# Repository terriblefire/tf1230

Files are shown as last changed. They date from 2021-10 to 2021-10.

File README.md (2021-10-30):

# tf1230

TF1230 source files. 

Released in Creative Commons CC-BY-ND license. 

This is a NO DERIVATIVES LICENSE. You cannot modify it and distribute the modified version.

TF1230 is distributed with absolutely no warranty. If you make a mistake you could blow up your A1200. I take no responsibility for this. 

The TF1230 is an 030 accelerator fixed at 50Mhz with 64Mb of SDRAM (128Mb possible), and is intended to work with CF cards or IDE2SD card type devices. The IDE interface does not work with long cables. It is intended to be CHEAP Because thats pretty much all Amiga users care about. You need the ehide.device to use the onboard ide.

There was a design decision to make with the TF ide. Do we make it work as the default ide device and break PCMCIA support, do we add a rom on the card (and more expense) or do we just provide a driver that you can put in a cheap rom and run that way (or just run from disk). I figured the cheapest and least invasive option was the best for a home build solution.

**Before you start building :- You can buy these from Supaduper & AlenPPC (AmiBay) completely built for less than it will cost you to buy the parts and the time it will take you if you bill your time at minimum wage.**

Also do not ask me to reroute the board to a different DRC so you can use your local boardhouse. I dont feel like spending 100 hours of my time to save you $10. The DRC on this board is 7-7-7 and any boardhouse that doesnt totally suck can do this. Also it 4 layer and dont ask if i can be made 2 layer. The answer is no. 

If you need help with this the best place to get it is the exxos forum https://www.exxoshost.co.uk/forum/ 

The SDRAM Controller is derived from my Archie core and the clock controller code is designed to simulate a PLL with adjustable phase. 

This is not an exercise in German over engineering. Its engineered to do an exact task and nothing more. You will need to do the timing fixes or put a clock buffer on the clock line on this board. I didnt do this because i believe that the timing changes are needed on Amigas and not doing them is bad for them long term. Cards that let you get away without doing it are doing you a diservice. It would be like cards letting you go longer without a recap. Its 

That said you are free to sell this on your webshop provided you give credit and do not vastly overprice it. However CE marking is your own issue not mine. AmigaKit may not sell this ever... anyone else can. 

On the other hand if you have an actual firmware bugfix send me a pull request with testing evidence. It will be appreciated greatly. 

For crashes please check that the crash doesnt happen in WinUAE for a A1200 with A1200 IDE and 64MB ZIII Ram before making a bug report. Most of the crashes we have seen over the years are repeatable in that environment.

The purpose of this card is for you to get more enjoyment from your Amiga for very little money. Please do that.

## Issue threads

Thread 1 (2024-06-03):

Possible to assert AS towards motherboard only if access is to low 16 MB?

niklasekstrom, 2024-06-03:
Hi @terriblefire,

A user of PicoWyfy (https://github.com/niklasekstrom/picowyfy) that has an issue when it is used together with TF1232 pointed me to this forum post: https://www.exxosforum.co.uk/forum/viewtopic.php?p=91790

Would it make sense to update the logic for the AS signal towards the motherboard, by only asserting it if the top 8 bits of the address bus is 8'h00?

Perhaps something like: `AS20_D <= AS30 | ~SPEED_D | (A[31:24] != 8'h00);`
(taken from https://github.com/terriblefire/tf1230/blob/main/rtl/main_top.v#L274)

I'm thinking that this should prevent SPARE_CS from being asserted when an access is made to some address $xxD8yyyy where xx != 00.

I should say that I only looked at the rtl very quickly, so this may be incorrect for multiple reasons.

terriblefire, 2024-06-03:
i spent an evening trying this with Rob Cranley. I could do that but the CS lines do not depend on AS. They decode whether or not AS is asserted

niklasekstrom, 2024-06-03:
Oh, right, sorry. I looked in this document, https://www.amigawiki.org/lib/exe/fetch.php?media=de:parts:gayle_specification.pdf, where it says:

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
(`Chip select is based purely on address decode and _AS`)

But then when looking in this document, https://github.com/nonarkitten/amiga_replacement_project/blob/master/gayle/gayle_r5.pdf, it is as you say, SPARE_CS is based purely on address decode.

However, in that last document (gayle_r5.pdf) it also looks like AS needs to be asserted for IORD to be asserted. So keeping AS negated should prevent IORD from becoming asserted, and so should prevent the incorrect read access from the clockport device.

Actually, although not strictly necessary, perhaps DS20 should also be gated by A[31:24] == 8'h00?

`DS20_D <= DS30 | ~SPEED_D | (A[31:24] != 8'h00);`
(From https://github.com/terriblefire/tf1230/blob/main/rtl/main_top.v#L275)

niklasekstrom, 2024-06-03:
Would it be easy (enough) for you to compile a firmware for TF1232 using these two changes (gating AS20_D and DS20_D)? In that case perhaps the guy who has the TF1232 + PicoWyfy combo could try that firmware and see if it helps.

terriblefire, 2024-06-03:
I can but you need to understand it's irrelevant because SPEED_D is asserted when talking to fastram and that already prevents AS going low. I've investigated this issue thoroughly already.

niklasekstrom, 2024-06-03:
SPEED_D (via ram_decode) doesn't seem to take A[26:24] into account though?

terriblefire, 2024-06-03:
0x08D80000 would not assert AS/DS because A27 is asserted. Anything in the range 08xxx xxxx will not assert AS. I've already measured this looking for this specific issue.

niklasekstrom, 2024-06-03:
Ah right, so the address 0x07D80000 would cause a problem though?

terriblefire, 2024-06-03:
Nothing in AmigaOS should look at that address.

terriblefire, 2024-06-03:
BTW. You can just try this yourself with the TF1230 code. The TF1232 is compatible with the TF1230 firmwares. You just dont get the FPU

niklasekstrom, 2024-06-03:
Do you have the build environment set up so that it's very easy for you to compile a new firmware with those changes?

If not then I could try to set it up myself. But if I do then I still don't have a way to compile the TF1232 firmware with FPU support, so the user doesn't have any way to restore the firmware to get FPU support back.

The user reported that the problem showed up in two demos, so the demos may make accesses that AmigaOS wouldn't.

Just to be clear, I have no idea if the problem has anything to do with the TF firmware, I'm just trying to think of things to test, to help the user out.

terriblefire, 2024-06-03:
I can put a test fw here. later if you need.

The reason i didnt want to blank off AS here is because technically the CPU slot is 32bit address bus and there are CFGIN/OUT pins on it. I guess most CPU cards wont obey the rules but you can put a full Z3 32bit bus card between all the TF cards and an amiga they will work. i.e. it will be able to address a card at 0x40000000 for example

niklasekstrom, 2024-06-03:
I checked with the guy, and he knows how to update the TF firmware as he did it recently. So if you could build a firmware with those changes then that would be most appreciated! And very interesting to see what happens.

niklasekstrom, 2024-06-04:
I managed to compile the firmware in this repo with the changes mentioned. But apparently there are other issues with the user's Amiga, so he hasn't been able to test the changes. Perhaps the crashes were related to the other issues to begin with.

I'll close this issue for now, and if he later manages to test the changes then I will add information about how it went.

terriblefire, 2024-06-04:
Ok thanks. if we can actually pin down an issue i'm happy to delve in and fix

Closed 2024-06-04.

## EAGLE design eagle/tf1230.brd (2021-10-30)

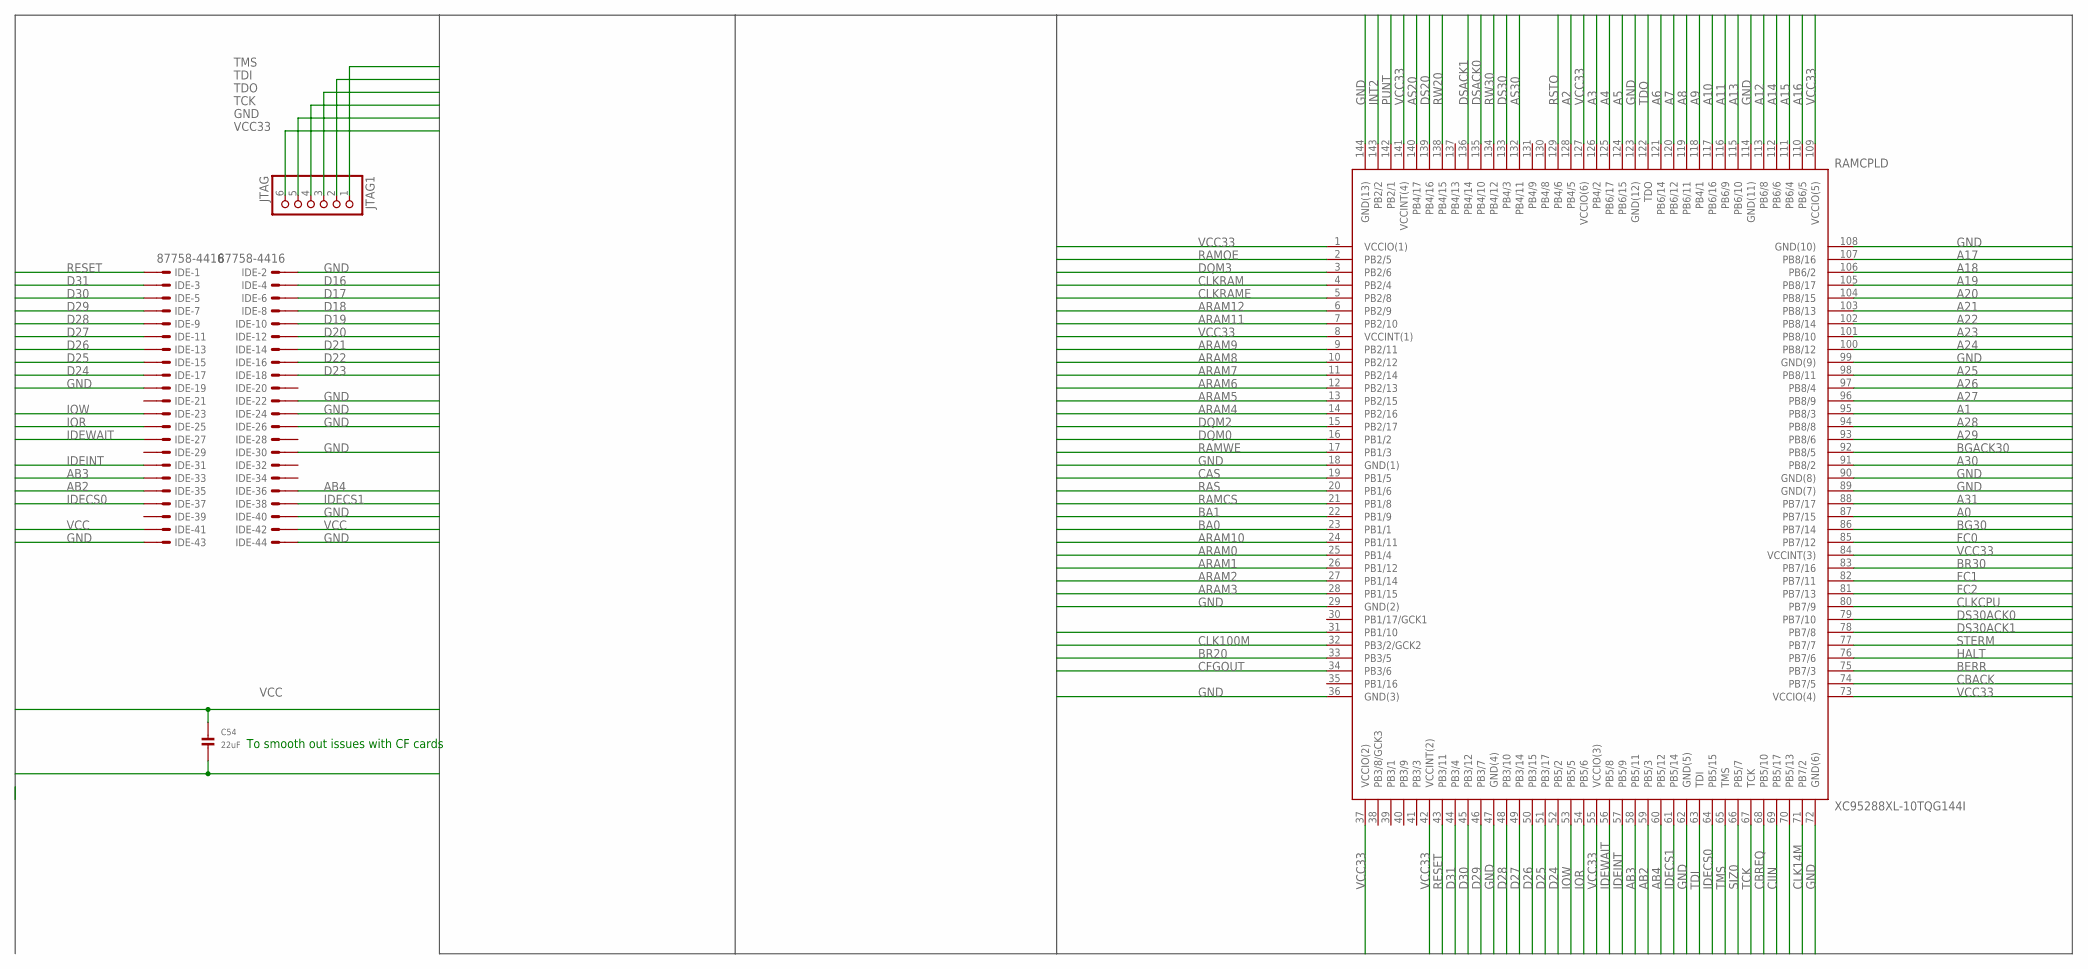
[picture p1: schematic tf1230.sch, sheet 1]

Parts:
C54: 22uF; 1206
IDE: 87758-4416
JTAG1: JTAG; 1X06_ROUND
RAMCPLD: XC95288XL-10TQG144I; SAMACSYS_PARTS_QFP50P2200X2200X160-144N

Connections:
A0: RAMCPLD.87 (PB7/15); also elsewhere on the board
A1: RAMCPLD.95 (PB8/3); also elsewhere on the board
A2: RAMCPLD.128 (PB4/5); also elsewhere on the board
A3: RAMCPLD.126 (PB4/2); also elsewhere on the board
A4: RAMCPLD.125 (PB6/17); also elsewhere on the board
A5: RAMCPLD.124 (PB6/15); also elsewhere on the board
A6: RAMCPLD.121 (PB6/14); also elsewhere on the board
A7: RAMCPLD.120 (PB6/12); also elsewhere on the board
A8: RAMCPLD.119 (PB6/11); also elsewhere on the board
A9: RAMCPLD.118 (PB4/1); also elsewhere on the board
A10: RAMCPLD.117 (PB6/16); also elsewhere on the board
A11: RAMCPLD.116 (PB6/9); also elsewhere on the board
A12: RAMCPLD.113 (PB6/8); also elsewhere on the board
A13: RAMCPLD.115 (PB6/10); also elsewhere on the board
A14: RAMCPLD.112 (PB6/6); also elsewhere on the board
A15: RAMCPLD.111 (PB6/4); also elsewhere on the board
A16: RAMCPLD.110 (PB6/5); also elsewhere on the board
A17: RAMCPLD.107 (PB8/16); also elsewhere on the board
A18: RAMCPLD.106 (PB6/2); also elsewhere on the board
A19: RAMCPLD.105 (PB8/17); also elsewhere on the board
A20: RAMCPLD.104 (PB8/15); also elsewhere on the board
A21: RAMCPLD.103 (PB8/13); also elsewhere on the board
A22: RAMCPLD.102 (PB8/14); also elsewhere on the board
A23: RAMCPLD.101 (PB8/10); also elsewhere on the board
A24: RAMCPLD.100 (PB8/12); also elsewhere on the board
A25: RAMCPLD.98 (PB8/11); also elsewhere on the board
A26: RAMCPLD.97 (PB8/4); also elsewhere on the board
A27: RAMCPLD.96 (PB8/9); also elsewhere on the board
A28: RAMCPLD.94 (PB8/8); also elsewhere on the board
A29: RAMCPLD.93 (PB8/6); also elsewhere on the board
A30: RAMCPLD.91 (PB8/2); also elsewhere on the board
A31: RAMCPLD.88 (PB7/17); also elsewhere on the board
AB2: IDE.35, RAMCPLD.59 (PB5/3)
AB3: IDE.33, RAMCPLD.58 (PB5/11)
AB4: IDE.36, RAMCPLD.60 (PB5/12)
ARAM0: RAMCPLD.25 (PB1/4); also elsewhere on the board
ARAM1: RAMCPLD.26 (PB1/12); also elsewhere on the board
ARAM2: RAMCPLD.27 (PB1/14); also elsewhere on the board
ARAM3: RAMCPLD.28 (PB1/15); also elsewhere on the board
ARAM4: RAMCPLD.14 (PB2/16); also elsewhere on the board
ARAM5: RAMCPLD.13 (PB2/15); also elsewhere on the board
ARAM6: RAMCPLD.12 (PB2/13); also elsewhere on the board
ARAM7: RAMCPLD.11 (PB2/14); also elsewhere on the board
ARAM8: RAMCPLD.10 (PB2/12); also elsewhere on the board
ARAM9: RAMCPLD.9 (PB2/11); also elsewhere on the board
ARAM10: RAMCPLD.24 (PB1/11); also elsewhere on the board
ARAM11: RAMCPLD.7 (PB2/10); also elsewhere on the board
ARAM12: RAMCPLD.6 (PB2/9); also elsewhere on the board
AS20: RAMCPLD.140 (PB4/17); also elsewhere on the board
AS30: RAMCPLD.132 (PB4/11); also elsewhere on the board
BA0: RAMCPLD.23 (PB1/1); also elsewhere on the board
BA1: RAMCPLD.22 (PB1/9); also elsewhere on the board
BERR: RAMCPLD.75 (PB7/3); also elsewhere on the board
BG30: RAMCPLD.86 (PB7/14); also elsewhere on the board
BGACK30: RAMCPLD.92 (PB8/5); also elsewhere on the board
BR20: RAMCPLD.33 (PB3/5); also elsewhere on the board
BR30: RAMCPLD.83 (PB7/16); also elsewhere on the board
CAS: RAMCPLD.19 (PB1/5); also elsewhere on the board
CBACK: RAMCPLD.74 (PB7/5); also elsewhere on the board
CBREQ: RAMCPLD.68 (PB5/10); also elsewhere on the board
CFGOUT: RAMCPLD.34 (PB3/6); also elsewhere on the board
CIIN: RAMCPLD.69 (PB5/17); also elsewhere on the board
CLK14M: RAMCPLD.71 (PB7/2); also elsewhere on the board
CLK100M: RAMCPLD.32 (PB3/2/GCK2); also elsewhere on the board
CLKCPU: RAMCPLD.80 (PB7/9); also elsewhere on the board
CLKRAM: RAMCPLD.4 (PB2/4); also elsewhere on the board
CLKRAME: RAMCPLD.5 (PB2/8); also elsewhere on the board
D16: IDE.4; also elsewhere on the board
D17: IDE.6; also elsewhere on the board
D18: IDE.8; also elsewhere on the board
D19: IDE.10; also elsewhere on the board
D20: IDE.12; also elsewhere on the board
D21: IDE.14; also elsewhere on the board
D22: IDE.16; also elsewhere on the board
D23: IDE.18; also elsewhere on the board
D24: IDE.17, RAMCPLD.52 (PB5/2); also elsewhere on the board
D25: IDE.15, RAMCPLD.51 (PB3/17); also elsewhere on the board
D26: IDE.13, RAMCPLD.50 (PB3/15); also elsewhere on the board
D27: IDE.11, RAMCPLD.49 (PB3/14); also elsewhere on the board
D28: IDE.9, RAMCPLD.48 (PB3/10); also elsewhere on the board
D29: IDE.7, RAMCPLD.46 (PB3/7); also elsewhere on the board
D30: IDE.5, RAMCPLD.45 (PB3/12); also elsewhere on the board
D31: IDE.3, RAMCPLD.44 (PB3/4); also elsewhere on the board
DQM0: RAMCPLD.16 (PB1/2); also elsewhere on the board
DQM1: RAMCPLD.31 (PB1/10); also elsewhere on the board
DQM2: RAMCPLD.15 (PB2/17); also elsewhere on the board
DQM3: RAMCPLD.3 (PB2/6); also elsewhere on the board
DS20: RAMCPLD.139 (PB4/16); also elsewhere on the board
DS30: RAMCPLD.133 (PB4/3); also elsewhere on the board
DS30ACK0: RAMCPLD.79 (PB7/10); also elsewhere on the board
DS30ACK1: RAMCPLD.78 (PB7/8); also elsewhere on the board
DSACK0: RAMCPLD.135 (PB4/10); also elsewhere on the board
DSACK1: RAMCPLD.136 (PB4/14); also elsewhere on the board
FC0: RAMCPLD.85 (PB7/12); also elsewhere on the board
FC1: RAMCPLD.82 (PB7/11); also elsewhere on the board
FC2: RAMCPLD.81 (PB7/13); also elsewhere on the board
GND: C54.2, IDE.2, IDE.19, IDE.22, IDE.24, IDE.26, IDE.30, IDE.40, IDE.43, IDE.44, JTAG1.5, RAMCPLD.18 (GND(1)), RAMCPLD.29 (GND(2)), RAMCPLD.36 (GND(3)), RAMCPLD.47 (GND(4)), RAMCPLD.62 (GND(5)), RAMCPLD.72 (GND(6)), RAMCPLD.89 (GND(7)), RAMCPLD.90 (GND(8)), RAMCPLD.99 (GND(9)), RAMCPLD.108 (GND(10)), RAMCPLD.114 (GND(11)), RAMCPLD.123 (GND(12)), RAMCPLD.144 (GND(13)); also elsewhere on the board
HALT: RAMCPLD.76 (PB7/6); also elsewhere on the board
IDECS0: IDE.37, RAMCPLD.64 (PB5/15)
IDECS1: IDE.38, RAMCPLD.61 (PB5/14)
IDEINT: IDE.31, RAMCPLD.57 (PB5/9); also elsewhere on the board
IDEWAIT: IDE.27, RAMCPLD.56 (PB5/8); also elsewhere on the board
INT2: RAMCPLD.143 (PB2/2); also elsewhere on the board
IOR: IDE.25, RAMCPLD.54 (PB5/6)
IOW: IDE.23, RAMCPLD.53 (PB5/5)
PUNT: RAMCPLD.142 (PB2/1); also elsewhere on the board
RAMCS: RAMCPLD.21 (PB1/8); also elsewhere on the board
RAMOE: RAMCPLD.2 (PB2/5); also elsewhere on the board
RAMWE: RAMCPLD.17 (PB1/3); also elsewhere on the board
RAS: RAMCPLD.20 (PB1/6); also elsewhere on the board
RESET: IDE.1, RAMCPLD.43 (PB3/11); also elsewhere on the board
RSTO: RAMCPLD.129 (PB4/6); also elsewhere on the board
RW20: RAMCPLD.138 (PB4/15); also elsewhere on the board
RW30: RAMCPLD.134 (PB4/12); also elsewhere on the board
SIZ0: RAMCPLD.66 (PB5/7); also elsewhere on the board
SIZ1: RAMCPLD.70 (PB5/13); also elsewhere on the board
STERM: RAMCPLD.77 (PB7/7); also elsewhere on the board
TCK: JTAG1.4, RAMCPLD.67 (TCK)
TDI: JTAG1.2, RAMCPLD.63 (TDI)
TDO: JTAG1.3, RAMCPLD.122 (TDO)
TMS: JTAG1.1, RAMCPLD.65 (TMS)
VCC: C54.1, IDE.41, IDE.42; also elsewhere on the board
VCC33: JTAG1.6, RAMCPLD.1 (VCCIO(1)), RAMCPLD.8 (VCCINT(1)), RAMCPLD.37 (VCCIO(2)), RAMCPLD.42 (VCCINT(2)), RAMCPLD.55 (VCCIO(3)), RAMCPLD.73 (VCCIO(4)), RAMCPLD.84 (VCCINT(3)), RAMCPLD.109 (VCCIO(5)), RAMCPLD.127 (VCCIO(6)), RAMCPLD.141 (VCCINT(4)); also elsewhere on the board

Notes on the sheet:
To smooth out issues with CF cards

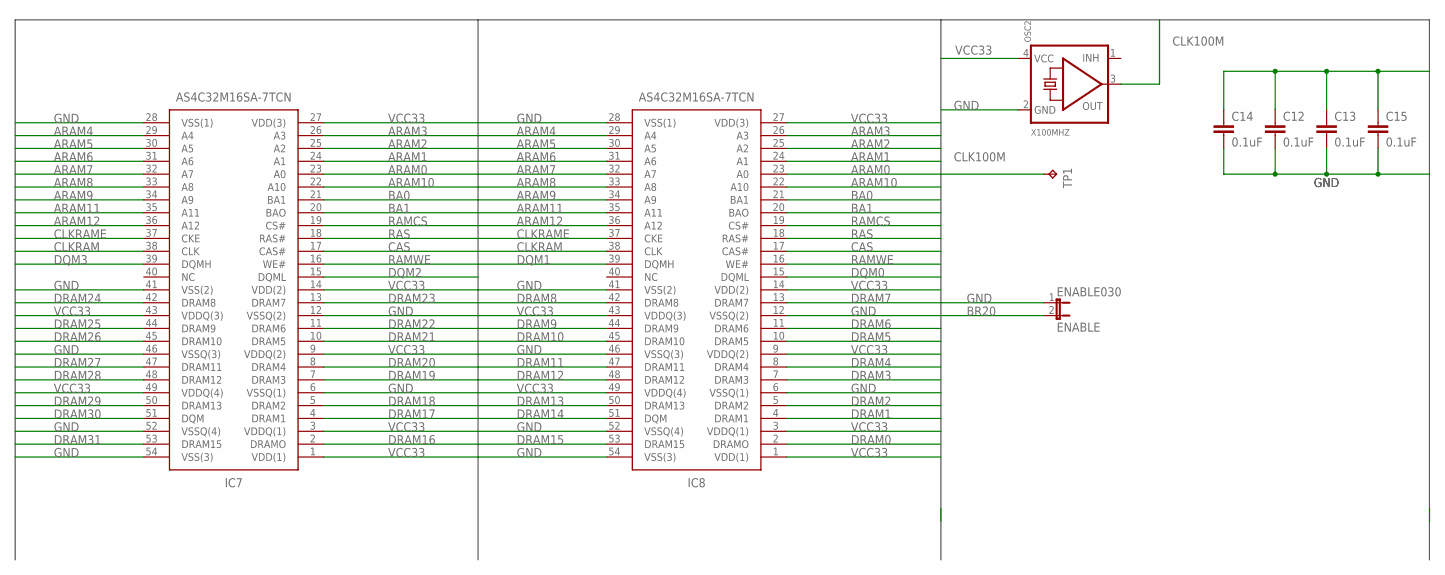
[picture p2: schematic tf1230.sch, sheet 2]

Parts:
C12, C13, C14, C15: 0.1uF; 0603-CAP
ENABLE030: ENABLE; 1X02
IC7, IC8: AS4C32M16SA-7TCN; SOP80P1176X120-54N
OSC2: X100MHZ; OSC_7X5MM
TP1: TPB1,27; B1,27

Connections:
ARAM0: IC7.23 (A0), IC8.23 (A0); also elsewhere on the board
ARAM1: IC7.24 (A1), IC8.24 (A1); also elsewhere on the board
ARAM2: IC7.25 (A2), IC8.25 (A2); also elsewhere on the board
ARAM3: IC7.26 (A3), IC8.26 (A3); also elsewhere on the board
ARAM4: IC7.29 (A4), IC8.29 (A4); also elsewhere on the board
ARAM5: IC7.30 (A5), IC8.30 (A5); also elsewhere on the board
ARAM6: IC7.31 (A6), IC8.31 (A6); also elsewhere on the board
ARAM7: IC7.32 (A7), IC8.32 (A7); also elsewhere on the board
ARAM8: IC7.33 (A8), IC8.33 (A8); also elsewhere on the board
ARAM9: IC7.34 (A9), IC8.34 (A9); also elsewhere on the board
ARAM10: IC7.22 (A10), IC8.22 (A10); also elsewhere on the board
ARAM11: IC7.35 (A11), IC8.35 (A11); also elsewhere on the board
ARAM12: IC7.36 (A12), IC8.36 (A12); also elsewhere on the board
BA0: IC7.21 (BA1), IC8.21 (BA1); also elsewhere on the board
BA1: IC7.20 (BAO), IC8.20 (BAO); also elsewhere on the board
BR20: ENABLE030.2; also elsewhere on the board
CAS: IC7.17 (CAS#), IC8.17 (CAS#); also elsewhere on the board
CLK100M: OSC2.3 (OUT), TP1.TP; also elsewhere on the board
CLKRAM: IC7.38 (CLK), IC8.38 (CLK); also elsewhere on the board
CLKRAME: IC7.37 (CKE), IC8.37 (CKE); also elsewhere on the board
DQM0: IC8.15 (DQML); also elsewhere on the board
DQM1: IC8.39 (DQMH); also elsewhere on the board
DQM2: IC7.15 (DQML); also elsewhere on the board
DQM3: IC7.39 (DQMH); also elsewhere on the board
DRAM0: IC8.2 (DRAMO); also elsewhere on the board
DRAM1: IC8.4 (DRAM1); also elsewhere on the board
DRAM2: IC8.5 (DRAM2); also elsewhere on the board
DRAM3: IC8.7 (DRAM3); also elsewhere on the board
DRAM4: IC8.8 (DRAM4); also elsewhere on the board
DRAM5: IC8.10 (DRAM5); also elsewhere on the board
DRAM6: IC8.11 (DRAM6); also elsewhere on the board
DRAM7: IC8.13 (DRAM7); also elsewhere on the board
DRAM8: IC8.42 (DRAM8); also elsewhere on the board
DRAM9: IC8.44 (DRAM9); also elsewhere on the board
DRAM10: IC8.45 (DRAM10); also elsewhere on the board
DRAM11: IC8.47 (DRAM11); also elsewhere on the board
DRAM12: IC8.48 (DRAM12); also elsewhere on the board
DRAM13: IC8.50 (DRAM13); also elsewhere on the board
DRAM14: IC8.51 (DQM); also elsewhere on the board
DRAM15: IC8.53 (DRAM15); also elsewhere on the board
DRAM16: IC7.2 (DRAMO); also elsewhere on the board
DRAM17: IC7.4 (DRAM1); also elsewhere on the board
DRAM18: IC7.5 (DRAM2); also elsewhere on the board
DRAM19: IC7.7 (DRAM3); also elsewhere on the board
DRAM20: IC7.8 (DRAM4); also elsewhere on the board
DRAM21: IC7.10 (DRAM5); also elsewhere on the board
DRAM22: IC7.11 (DRAM6); also elsewhere on the board
DRAM23: IC7.13 (DRAM7); also elsewhere on the board
DRAM24: IC7.42 (DRAM8); also elsewhere on the board
DRAM25: IC7.44 (DRAM9); also elsewhere on the board
DRAM26: IC7.45 (DRAM10); also elsewhere on the board
DRAM27: IC7.47 (DRAM11); also elsewhere on the board
DRAM28: IC7.48 (DRAM12); also elsewhere on the board
DRAM29: IC7.50 (DRAM13); also elsewhere on the board
DRAM30: IC7.51 (DQM); also elsewhere on the board
DRAM31: IC7.53 (DRAM15); also elsewhere on the board
GND: C12.2, C13.2, C14.2, C15.2, ENABLE030.1, IC7.6 (VSSQ(1)), IC7.12 (VSSQ(2)), IC7.28 (VSS(1)), IC7.41 (VSS(2)), IC7.46 (VSSQ(3)), IC7.52 (VSSQ(4)), IC7.54 (VSS(3)), IC8.6 (VSSQ(1)), IC8.12 (VSSQ(2)), IC8.28 (VSS(1)), IC8.41 (VSS(2)), IC8.46 (VSSQ(3)), IC8.52 (VSSQ(4)), IC8.54 (VSS(3)), OSC2.2 (GND); also elsewhere on the board
RAMCS: IC7.19 (CS#), IC8.19 (CS#); also elsewhere on the board
RAMWE: IC7.16 (WE#), IC8.16 (WE#); also elsewhere on the board
RAS: IC7.18 (RAS#), IC8.18 (RAS#); also elsewhere on the board
VCC: C12.1, C13.1, C14.1, C15.1; also elsewhere on the board
VCC33: IC7.1 (VDD(1)), IC7.3 (VDDQ(1)), IC7.9 (VDDQ(2)), IC7.14 (VDD(2)), IC7.27 (VDD(3)), IC7.43 (VDDQ(3)), IC7.49 (VDDQ(4)), IC8.1 (VDD(1)), IC8.3 (VDDQ(1)), IC8.9 (VDDQ(2)), IC8.14 (VDD(2)), IC8.27 (VDD(3)), IC8.43 (VDDQ(3)), IC8.49 (VDDQ(4)), OSC2.4 (VCC); also elsewhere on the board

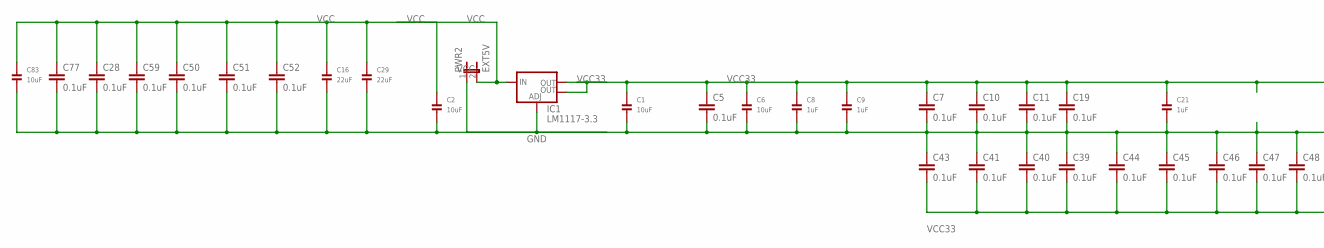
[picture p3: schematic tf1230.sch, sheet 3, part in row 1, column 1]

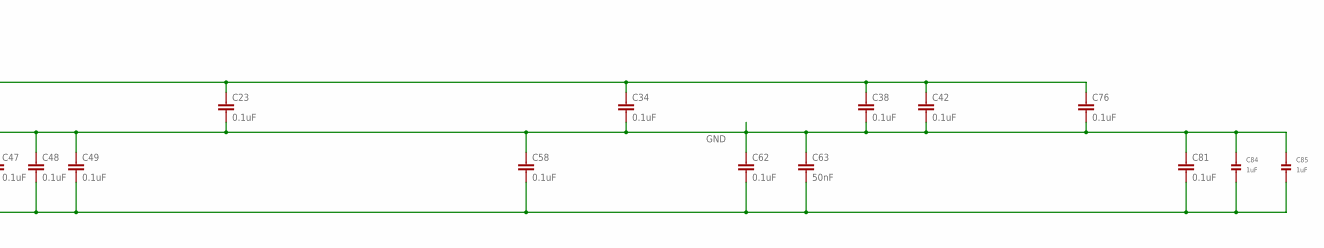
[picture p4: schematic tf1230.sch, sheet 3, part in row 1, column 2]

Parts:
C1, C2, C6, C83: 10uF; 1206
C5, C7, C10, C11, C19, C23, C28, C34, C38, C39, C40, C41, C42, C43, C44, C45, C46, C47, C48, C49, C50, C51, C52, C58, C59, C62, C76, C77, C81: 0.1uF; 0603-CAP
C8, C9, C21, C84, C85: 1uF; 1206
C16, C29: 22uF; 1206
C63: 50nF; 0603-CAP
IC1: LM1117-3.3; SOT223
PWR2: EXT5V; 1X02

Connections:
GND: C1.2, C2.2, C5.2, C6.2, C7.2, C8.2, C9.2, C10.2, C11.2, C16.2, C19.2, C21.2, C23.2, C28.2, C29.2, C34.2, C38.2, C39.1, C40.1, C41.1, C42.2, C43.1, C44.1, C45.1, C46.1, C47.1, C48.1, C49.1, C50.2, C51.2, C52.2, C58.1, C59.2, C62.1, C63.1, C76.2, C77.2, C81.1, C83.2, C84.1, C85.1, IC1.1 (ADJ), PWR2.1; also elsewhere on the board
VCC: C2.1, C16.1, C28.1, C29.1, C50.1, C51.1, C52.1, C59.1, C77.1, C83.1, IC1.3 (IN), PWR2.2; also elsewhere on the board
VCC33: C1.1, C5.1, C6.1, C7.1, C8.1, C9.1, C10.1, C11.1, C19.1, C21.1, C23.1, C34.1, C38.1, C39.2, C40.2, C41.2, C42.1, C43.2, C44.2, C45.2, C46.2, C47.2, C48.2, C49.2, C58.2, C62.2, C63.2, C76.1, C81.2, C84.2, C85.2, IC1.2 (OUT), IC1.4 (OUT); also elsewhere on the board

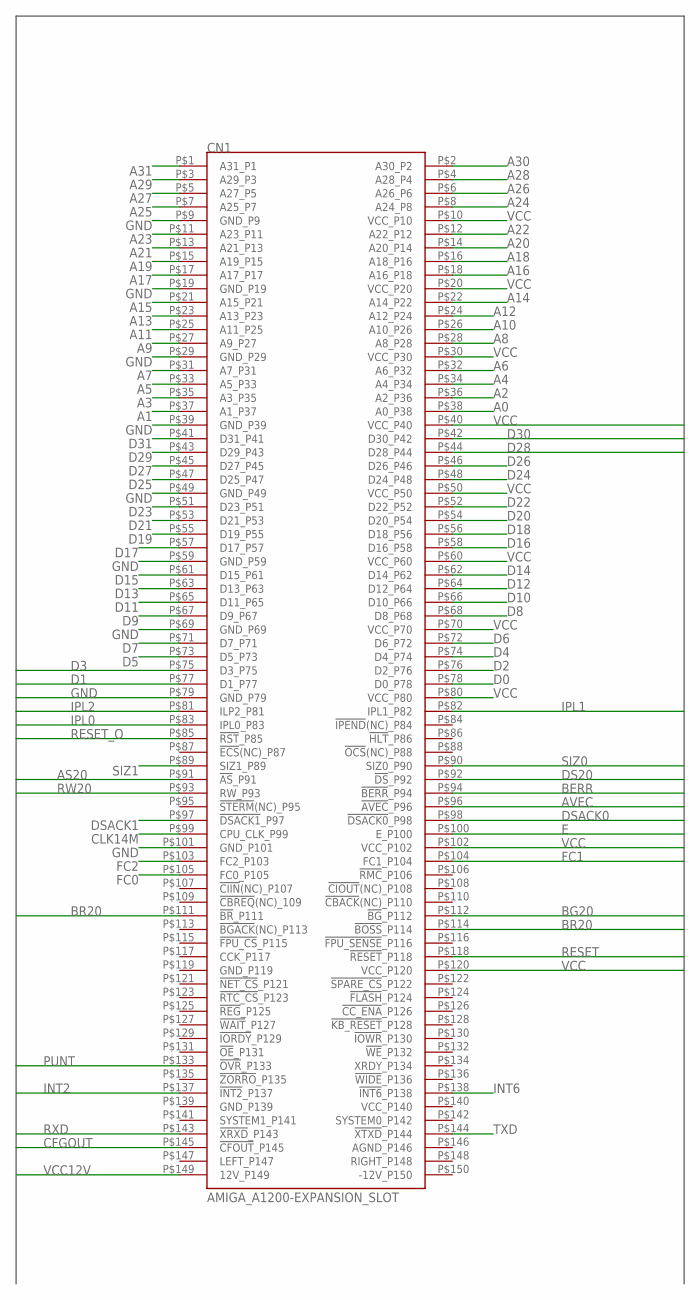
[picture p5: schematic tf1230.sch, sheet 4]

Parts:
CN1: AMIGA_A1200-EXPANSION_SLOT; AMIGA_CON_150

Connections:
A0: CN1.P$38 (A0_P38); also elsewhere on the board
A1: CN1.P$37 (A1_P37); also elsewhere on the board
A2: CN1.P$36 (A2_P36); also elsewhere on the board
A3: CN1.P$35 (A3_P35); also elsewhere on the board
A4: CN1.P$34 (A4_P34); also elsewhere on the board
A5: CN1.P$33 (A5_P33); also elsewhere on the board
A6: CN1.P$32 (A6_P32); also elsewhere on the board
A7: CN1.P$31 (A7_P31); also elsewhere on the board
A8: CN1.P$28 (A8_P28); also elsewhere on the board
A9: CN1.P$27 (A9_P27); also elsewhere on the board
A10: CN1.P$26 (A10_P26); also elsewhere on the board
A11: CN1.P$25 (A11_P25); also elsewhere on the board
A12: CN1.P$24 (A12_P24); also elsewhere on the board
A13: CN1.P$23 (A13_P23); also elsewhere on the board
A14: CN1.P$22 (A14_P22); also elsewhere on the board
A15: CN1.P$21 (A15_P21); also elsewhere on the board
A16: CN1.P$18 (A16_P18); also elsewhere on the board
A17: CN1.P$17 (A17_P17); also elsewhere on the board
A18: CN1.P$16 (A18_P16); also elsewhere on the board
A19: CN1.P$15 (A19_P15); also elsewhere on the board
A20: CN1.P$14 (A20_P14); also elsewhere on the board
A21: CN1.P$13 (A21_P13); also elsewhere on the board
A22: CN1.P$12 (A22_P12); also elsewhere on the board
A23: CN1.P$11 (A23_P11); also elsewhere on the board
A24: CN1.P$8 (A24_P8); also elsewhere on the board
A25: CN1.P$7 (A25_P7); also elsewhere on the board
A26: CN1.P$6 (A26_P6); also elsewhere on the board
A27: CN1.P$5 (A27_P5); also elsewhere on the board
A28: CN1.P$4 (A28_P4); also elsewhere on the board
A29: CN1.P$3 (A29_P3); also elsewhere on the board
A30: CN1.P$2 (A30_P2); also elsewhere on the board
A31: CN1.P$1 (A31_P1); also elsewhere on the board
AS20: CN1.P$91 (!AS!_P91); also elsewhere on the board
AVEC: CN1.P$96 (!AVEC!_P96); also elsewhere on the board
BERR: CN1.P$94 (!BERR!_P94); also elsewhere on the board
BG20: CN1.P$112 (!BG!_P112)
BR20: CN1.P$111 (!BR!_P111), CN1.P$114 (!BOSS!_P114); also elsewhere on the board
CFGOUT: CN1.P$145 (!CFOUT!_P145); also elsewhere on the board
CLK14M: CN1.P$99 (CPU_CLK_P99); also elsewhere on the board
D0: CN1.P$78 (D0_P78); also elsewhere on the board
D1: CN1.P$77 (D1_P77); also elsewhere on the board
D2: CN1.P$76 (D2_P76); also elsewhere on the board
D3: CN1.P$75 (D3_P75); also elsewhere on the board
D4: CN1.P$74 (D4_P74); also elsewhere on the board
D5: CN1.P$73 (D5_P73); also elsewhere on the board
D6: CN1.P$72 (D6_P72); also elsewhere on the board
D7: CN1.P$71 (D7_P71); also elsewhere on the board
D8: CN1.P$68 (D8_P68); also elsewhere on the board
D9: CN1.P$67 (D9_P67); also elsewhere on the board
D10: CN1.P$66 (D10_P66); also elsewhere on the board
D11: CN1.P$65 (D11_P65); also elsewhere on the board
D12: CN1.P$64 (D12_P64); also elsewhere on the board
D13: CN1.P$63 (D13_P63); also elsewhere on the board
D14: CN1.P$62 (D14_P62); also elsewhere on the board
D15: CN1.P$61 (D15_P61); also elsewhere on the board
D16: CN1.P$58 (D16_P58); also elsewhere on the board
D17: CN1.P$57 (D17_P57); also elsewhere on the board
D18: CN1.P$56 (D18_P56); also elsewhere on the board
D19: CN1.P$55 (D19_P55); also elsewhere on the board
D20: CN1.P$54 (D20_P54); also elsewhere on the board
D21: CN1.P$53 (D21_P53); also elsewhere on the board
D22: CN1.P$52 (D22_P52); also elsewhere on the board
D23: CN1.P$51 (D23_P51); also elsewhere on the board
D24: CN1.P$48 (D24_P48); also elsewhere on the board
D25: CN1.P$47 (D25_P47); also elsewhere on the board
D26: CN1.P$46 (D26_P46); also elsewhere on the board
D27: CN1.P$45 (D27_P45); also elsewhere on the board
D28: CN1.P$44 (D28_P44); also elsewhere on the board
D29: CN1.P$43 (D29_P43); also elsewhere on the board
D30: CN1.P$42 (D30_P42); also elsewhere on the board
D31: CN1.P$41 (D31_P41); also elsewhere on the board
DS20: CN1.P$92 (!DS!_P92); also elsewhere on the board
DSACK0: CN1.P$98 (!DSACK0!_P98); also elsewhere on the board
DSACK1: CN1.P$97 (!DSACK1!_P97); also elsewhere on the board
E: CN1.P$100 (E_P100)
FC0: CN1.P$105 (FC0_P105); also elsewhere on the board
FC1: CN1.P$104 (FC1_P104); also elsewhere on the board
FC2: CN1.P$103 (FC2_P103); also elsewhere on the board
GND: CN1.P$9 (GND_P9), CN1.P$19 (GND_P19), CN1.P$29 (GND_P29), CN1.P$39 (GND_P39), CN1.P$49 (GND_P49), CN1.P$59 (GND_P59), CN1.P$69 (GND_P69), CN1.P$79 (GND_P79), CN1.P$101 (GND_P101); also elsewhere on the board
INT2: CN1.P$137 (!INT2!_P137); also elsewhere on the board
INT6: CN1.P$138 (!INT6!_P138)
IPL0: CN1.P$83 (IPL0_P83); also elsewhere on the board
IPL1: CN1.P$82 (IPL1_P82); also elsewhere on the board
IPL2: CN1.P$81 (ILP2_P81); also elsewhere on the board
PUNT: CN1.P$133 (!OVR!_P133); also elsewhere on the board
RESET: CN1.P$118 (!RESET!_P118); also elsewhere on the board
RESET_O: CN1.P$85 (!RST!_P85); also elsewhere on the board
RW20: CN1.P$93 (RW_P93); also elsewhere on the board
RXD: CN1.P$143 (!XRXD!_P143)
SIZ0: CN1.P$90 (SIZ0_P90); also elsewhere on the board
SIZ1: CN1.P$89 (SIZ1_P89); also elsewhere on the board
TXD: CN1.P$144 (!XTXD!_P144)
VCC: CN1.P$10 (VCC_P10), CN1.P$20 (VCC_P20), CN1.P$30 (VCC_P30), CN1.P$40 (VCC_P40), CN1.P$50 (VCC_P50), CN1.P$60 (VCC_P60), CN1.P$70 (VCC_P70), CN1.P$80 (VCC_P80), CN1.P$102 (VCC_P102), CN1.P$120 (VCC_P120); also elsewhere on the board
VCC12V: CN1.P$149 (12V_P149)

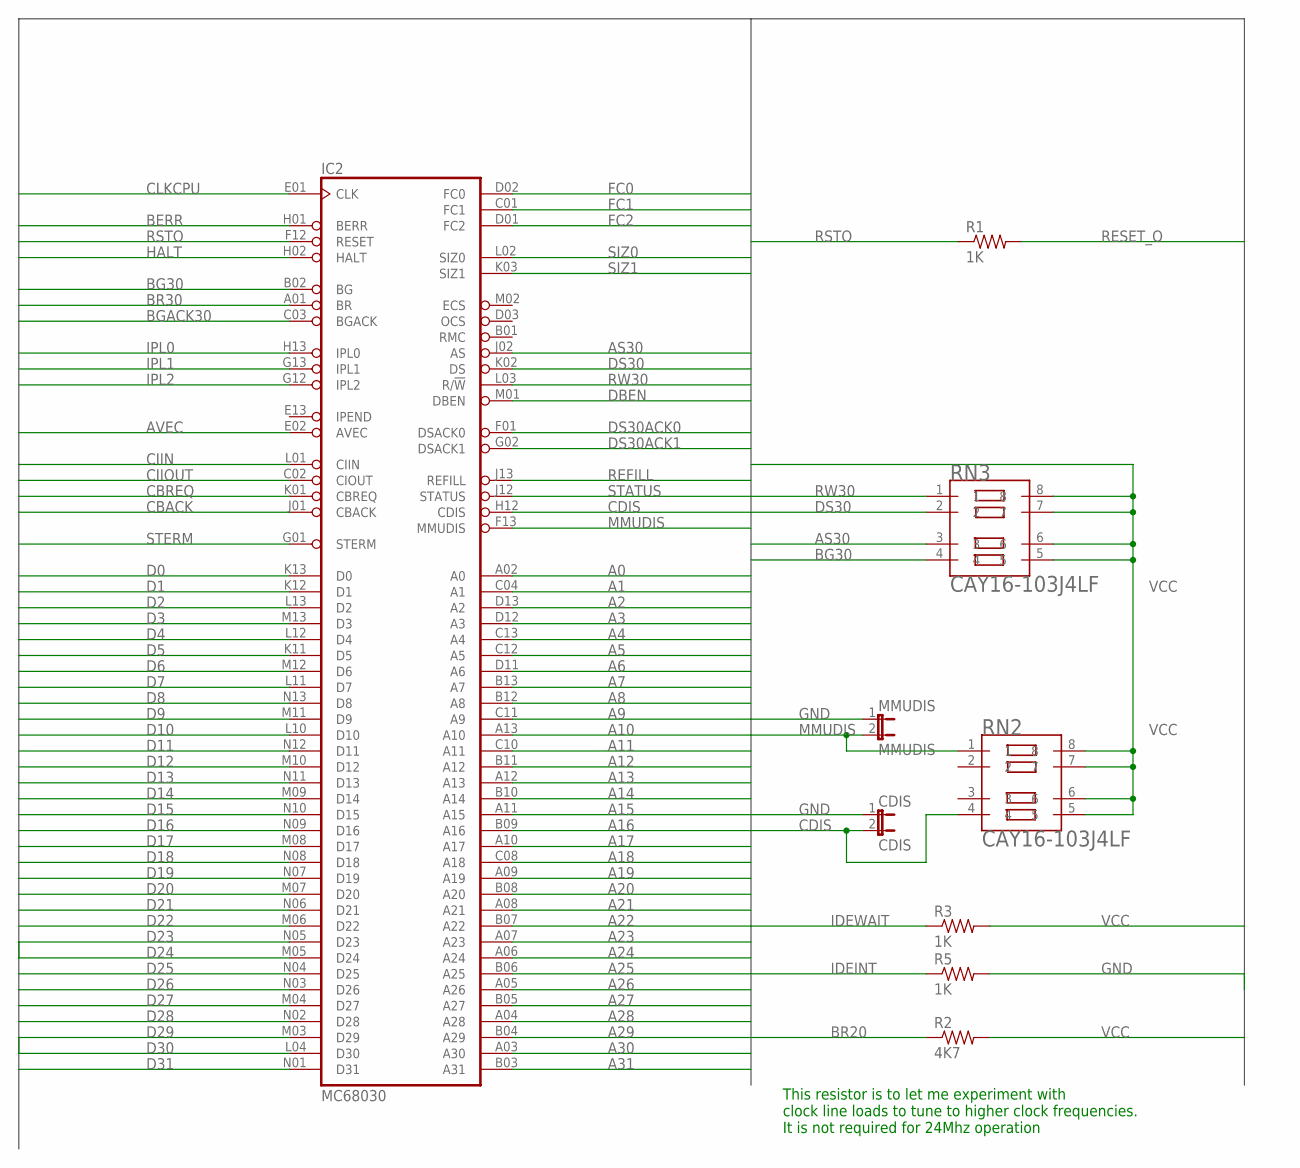
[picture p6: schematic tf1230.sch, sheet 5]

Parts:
CDIS: CDIS; 1X02
IC2: MC68030; MPGA128
MMUDIS: MMUDIS; 1X02
R1, R3, R5: 1K; 0603
R2: 4K7; 0603
RN2, RN3: CAY16-103J4LF; RESCAXE80P320X160-8N

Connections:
A0: IC2.A02 (A0); also elsewhere on the board
A1: IC2.C04 (A1); also elsewhere on the board
A2: IC2.D13 (A2); also elsewhere on the board
A3: IC2.D12 (A3); also elsewhere on the board
A4: IC2.C13 (A4); also elsewhere on the board
A5: IC2.C12 (A5); also elsewhere on the board
A6: IC2.D11 (A6); also elsewhere on the board
A7: IC2.B13 (A7); also elsewhere on the board
A8: IC2.B12 (A8); also elsewhere on the board
A9: IC2.C11 (A9); also elsewhere on the board
A10: IC2.A13 (A10); also elsewhere on the board
A11: IC2.C10 (A11); also elsewhere on the board
A12: IC2.B11 (A12); also elsewhere on the board
A13: IC2.A12 (A13); also elsewhere on the board
A14: IC2.B10 (A14); also elsewhere on the board
A15: IC2.A11 (A15); also elsewhere on the board
A16: IC2.B09 (A16); also elsewhere on the board
A17: IC2.A10 (A17); also elsewhere on the board
A18: IC2.C08 (A18); also elsewhere on the board
A19: IC2.A09 (A19); also elsewhere on the board
A20: IC2.B08 (A20); also elsewhere on the board
A21: IC2.A08 (A21); also elsewhere on the board
A22: IC2.B07 (A22); also elsewhere on the board
A23: IC2.A07 (A23); also elsewhere on the board
A24: IC2.A06 (A24); also elsewhere on the board
A25: IC2.B06 (A25); also elsewhere on the board
A26: IC2.A05 (A26); also elsewhere on the board
A27: IC2.B05 (A27); also elsewhere on the board
A28: IC2.A04 (A28); also elsewhere on the board
A29: IC2.B04 (A29); also elsewhere on the board
A30: IC2.A03 (A30); also elsewhere on the board
A31: IC2.B03 (A31); also elsewhere on the board
AS30: IC2.J02 (AS), RN3.3; also elsewhere on the board
AVEC: IC2.E02 (AVEC); also elsewhere on the board
BERR: IC2.H01 (BERR); also elsewhere on the board
BG30: IC2.B02 (BG), RN3.4; also elsewhere on the board
BGACK30: IC2.C03 (BGACK); also elsewhere on the board
BR20: R2.1; also elsewhere on the board
BR30: IC2.A01 (BR); also elsewhere on the board
CBACK: IC2.J01 (CBACK); also elsewhere on the board
CBREQ: IC2.K01 (CBREQ); also elsewhere on the board
CDIS: CDIS.2, IC2.H12 (CDIS), RN2.4
CIIN: IC2.L01 (CIIN); also elsewhere on the board
CIIOUT: IC2.C02 (CIOUT)
CLKCPU: IC2.E01 (CLK); also elsewhere on the board
D0: IC2.K13 (D0); also elsewhere on the board
D1: IC2.K12 (D1); also elsewhere on the board
D2: IC2.L13 (D2); also elsewhere on the board
D3: IC2.M13 (D3); also elsewhere on the board
D4: IC2.L12 (D4); also elsewhere on the board
D5: IC2.K11 (D5); also elsewhere on the board
D6: IC2.M12 (D6); also elsewhere on the board
D7: IC2.L11 (D7); also elsewhere on the board
D8: IC2.N13 (D8); also elsewhere on the board
D9: IC2.M11 (D9); also elsewhere on the board
D10: IC2.L10 (D10); also elsewhere on the board
D11: IC2.N12 (D11); also elsewhere on the board
D12: IC2.M10 (D12); also elsewhere on the board
D13: IC2.N11 (D13); also elsewhere on the board
D14: IC2.M09 (D14); also elsewhere on the board
D15: IC2.N10 (D15); also elsewhere on the board
D16: IC2.N09 (D16); also elsewhere on the board
D17: IC2.M08 (D17); also elsewhere on the board
D18: IC2.N08 (D18); also elsewhere on the board
D19: IC2.N07 (D19); also elsewhere on the board
D20: IC2.M07 (D20); also elsewhere on the board
D21: IC2.N06 (D21); also elsewhere on the board
D22: IC2.M06 (D22); also elsewhere on the board
D23: IC2.N05 (D23); also elsewhere on the board
D24: IC2.M05 (D24); also elsewhere on the board
D25: IC2.N04 (D25); also elsewhere on the board
D26: IC2.N03 (D26); also elsewhere on the board
D27: IC2.M04 (D27); also elsewhere on the board
D28: IC2.N02 (D28); also elsewhere on the board
D29: IC2.M03 (D29); also elsewhere on the board
D30: IC2.L04 (D30); also elsewhere on the board
D31: IC2.N01 (D31); also elsewhere on the board
DBEN: IC2.M01 (DBEN)
DS30: IC2.K02 (DS), RN3.2; also elsewhere on the board
DS30ACK0: IC2.F01 (DSACK0); also elsewhere on the board
DS30ACK1: IC2.G02 (DSACK1); also elsewhere on the board
FC0: IC2.D02 (FC0); also elsewhere on the board
FC1: IC2.C01 (FC1); also elsewhere on the board
FC2: IC2.D01 (FC2); also elsewhere on the board
GND: CDIS.1, IC2.C05 (GND), IC2.C07 (GND), IC2.C09 (GND), IC2.E03 (GND), IC2.E11 (GND), IC2.F03 (GND), IC2.G03 (GND), IC2.G11 (GND), IC2.J03 (GND), IC2.J11 (GND), IC2.L05 (GND), IC2.L07 (GND), IC2.L08 (GND), IC2.L09 (GND), MMUDIS.1, R5.2; also elsewhere on the board
HALT: IC2.H02 (HALT); also elsewhere on the board
IDEINT: R5.1; also elsewhere on the board
IDEWAIT: R3.1; also elsewhere on the board
IPL0: IC2.H13 (IPL0); also elsewhere on the board
IPL1: IC2.G13 (IPL1); also elsewhere on the board
IPL2: IC2.G12 (IPL2); also elsewhere on the board
MMUDIS: IC2.F13 (MMUDIS), MMUDIS.2, RN2.1
REFILL: IC2.J13 (REFILL)
RESET_O: R1.2; also elsewhere on the board
RSTO: IC2.F12 (RESET), R1.1; also elsewhere on the board
RW30: IC2.L03 (R/!W), RN3.1; also elsewhere on the board
SIZ0: IC2.L02 (SIZ0); also elsewhere on the board
SIZ1: IC2.K03 (SIZ1); also elsewhere on the board
STATUS: IC2.J12 (STATUS)
STERM: IC2.G01 (STERM); also elsewhere on the board
VCC: IC2.C06 (VCC), IC2.D04 (VCC), IC2.D10 (VCC), IC2.F02 (VCC), IC2.F11 (VCC), IC2.H03 (VCC), IC2.H11 (VCC), IC2.K04 (VCC), IC2.K10 (VCC), IC2.L06 (VCC), R2.2, R3.2, RN2.5, RN2.6, RN2.7, RN2.8, RN3.5, RN3.6, RN3.7, RN3.8; also elsewhere on the board

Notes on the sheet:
This resistor is to let me experiment with clock line loads to tune to higher clock frequencies. It is not required for 24Mhz operation

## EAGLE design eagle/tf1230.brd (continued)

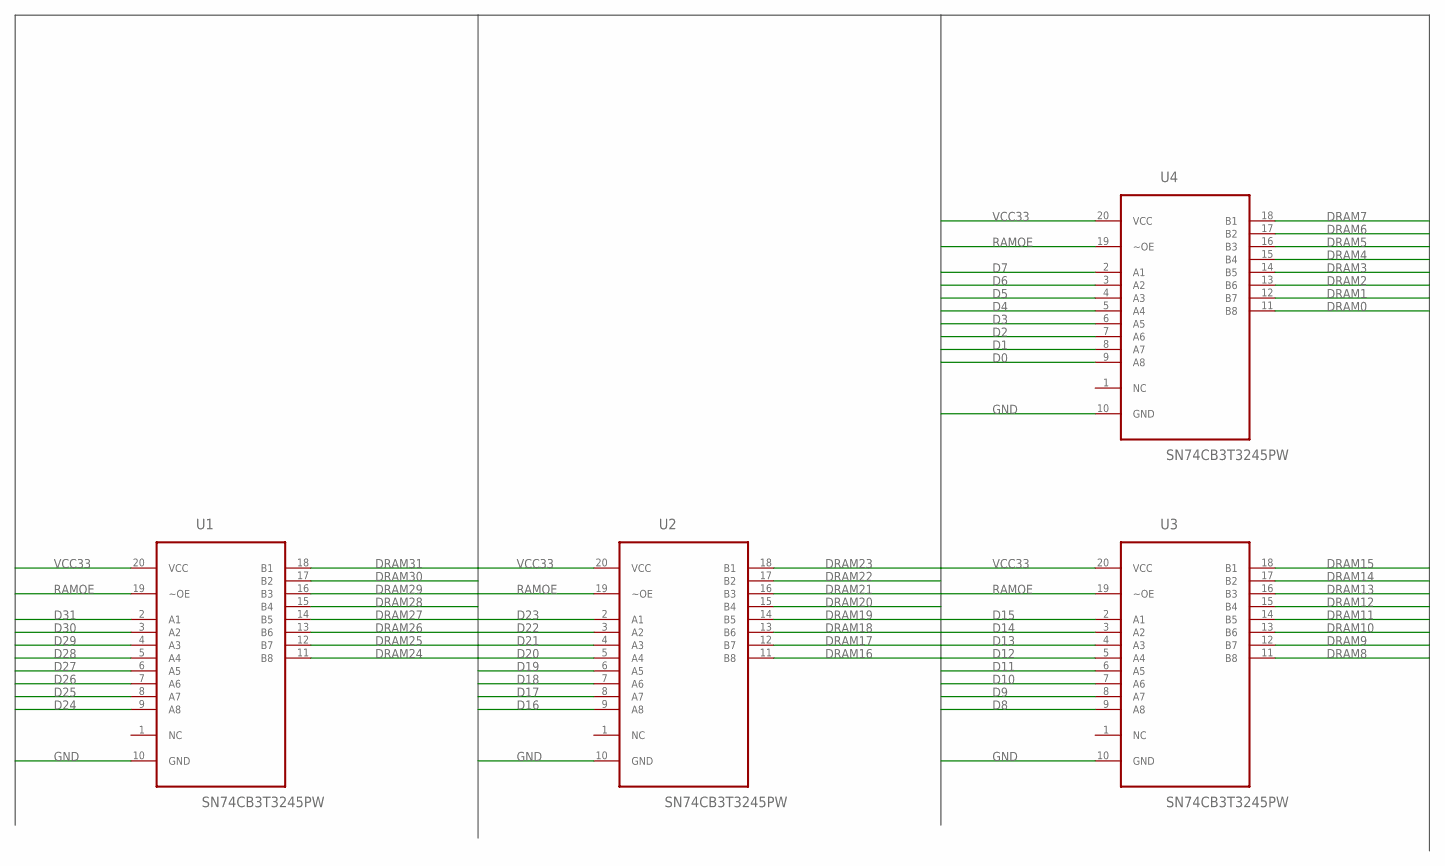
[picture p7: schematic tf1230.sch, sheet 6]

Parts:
U1, U2, U3, U4: SN74CB3T3245PW; SOP65P640X120-20N

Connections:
D0: U4.9 (A8); also elsewhere on the board
D1: U4.8 (A7); also elsewhere on the board
D2: U4.7 (A6); also elsewhere on the board
D3: U4.6 (A5); also elsewhere on the board
D4: U4.5 (A4); also elsewhere on the board
D5: U4.4 (A3); also elsewhere on the board
D6: U4.3 (A2); also elsewhere on the board
D7: U4.2 (A1); also elsewhere on the board
D8: U3.9 (A8); also elsewhere on the board
D9: U3.8 (A7); also elsewhere on the board
D10: U3.7 (A6); also elsewhere on the board
D11: U3.6 (A5); also elsewhere on the board
D12: U3.5 (A4); also elsewhere on the board
D13: U3.4 (A3); also elsewhere on the board
D14: U3.3 (A2); also elsewhere on the board
D15: U3.2 (A1); also elsewhere on the board
D16: U2.9 (A8); also elsewhere on the board
D17: U2.8 (A7); also elsewhere on the board
D18: U2.7 (A6); also elsewhere on the board
D19: U2.6 (A5); also elsewhere on the board
D20: U2.5 (A4); also elsewhere on the board
D21: U2.4 (A3); also elsewhere on the board
D22: U2.3 (A2); also elsewhere on the board
D23: U2.2 (A1); also elsewhere on the board
D24: U1.9 (A8); also elsewhere on the board
D25: U1.8 (A7); also elsewhere on the board
D26: U1.7 (A6); also elsewhere on the board
D27: U1.6 (A5); also elsewhere on the board
D28: U1.5 (A4); also elsewhere on the board
D29: U1.4 (A3); also elsewhere on the board
D30: U1.3 (A2); also elsewhere on the board
D31: U1.2 (A1); also elsewhere on the board
DRAM0: U4.11 (B8); also elsewhere on the board
DRAM1: U4.12 (B7); also elsewhere on the board
DRAM2: U4.13 (B6); also elsewhere on the board
DRAM3: U4.14 (B5); also elsewhere on the board
DRAM4: U4.15 (B4); also elsewhere on the board
DRAM5: U4.16 (B3); also elsewhere on the board
DRAM6: U4.17 (B2); also elsewhere on the board
DRAM7: U4.18 (B1); also elsewhere on the board
DRAM8: U3.11 (B8); also elsewhere on the board
DRAM9: U3.12 (B7); also elsewhere on the board
DRAM10: U3.13 (B6); also elsewhere on the board
DRAM11: U3.14 (B5); also elsewhere on the board
DRAM12: U3.15 (B4); also elsewhere on the board
DRAM13: U3.16 (B3); also elsewhere on the board
DRAM14: U3.17 (B2); also elsewhere on the board
DRAM15: U3.18 (B1); also elsewhere on the board
DRAM16: U2.11 (B8); also elsewhere on the board
DRAM17: U2.12 (B7); also elsewhere on the board
DRAM18: U2.13 (B6); also elsewhere on the board
DRAM19: U2.14 (B5); also elsewhere on the board
DRAM20: U2.15 (B4); also elsewhere on the board
DRAM21: U2.16 (B3); also elsewhere on the board
DRAM22: U2.17 (B2); also elsewhere on the board
DRAM23: U2.18 (B1); also elsewhere on the board
DRAM24: U1.11 (B8); also elsewhere on the board
DRAM25: U1.12 (B7); also elsewhere on the board
DRAM26: U1.13 (B6); also elsewhere on the board
DRAM27: U1.14 (B5); also elsewhere on the board
DRAM28: U1.15 (B4); also elsewhere on the board
DRAM29: U1.16 (B3); also elsewhere on the board
DRAM30: U1.17 (B2); also elsewhere on the board
DRAM31: U1.18 (B1); also elsewhere on the board
GND: U1.10 (GND), U2.10 (GND), U3.10 (GND), U4.10 (GND); also elsewhere on the board
RAMOE: U1.19 (~OE), U2.19 (~OE), U3.19 (~OE), U4.19 (~OE); also elsewhere on the board
VCC33: U1.20 (VCC), U2.20 (VCC), U3.20 (VCC), U4.20 (VCC); also elsewhere on the board

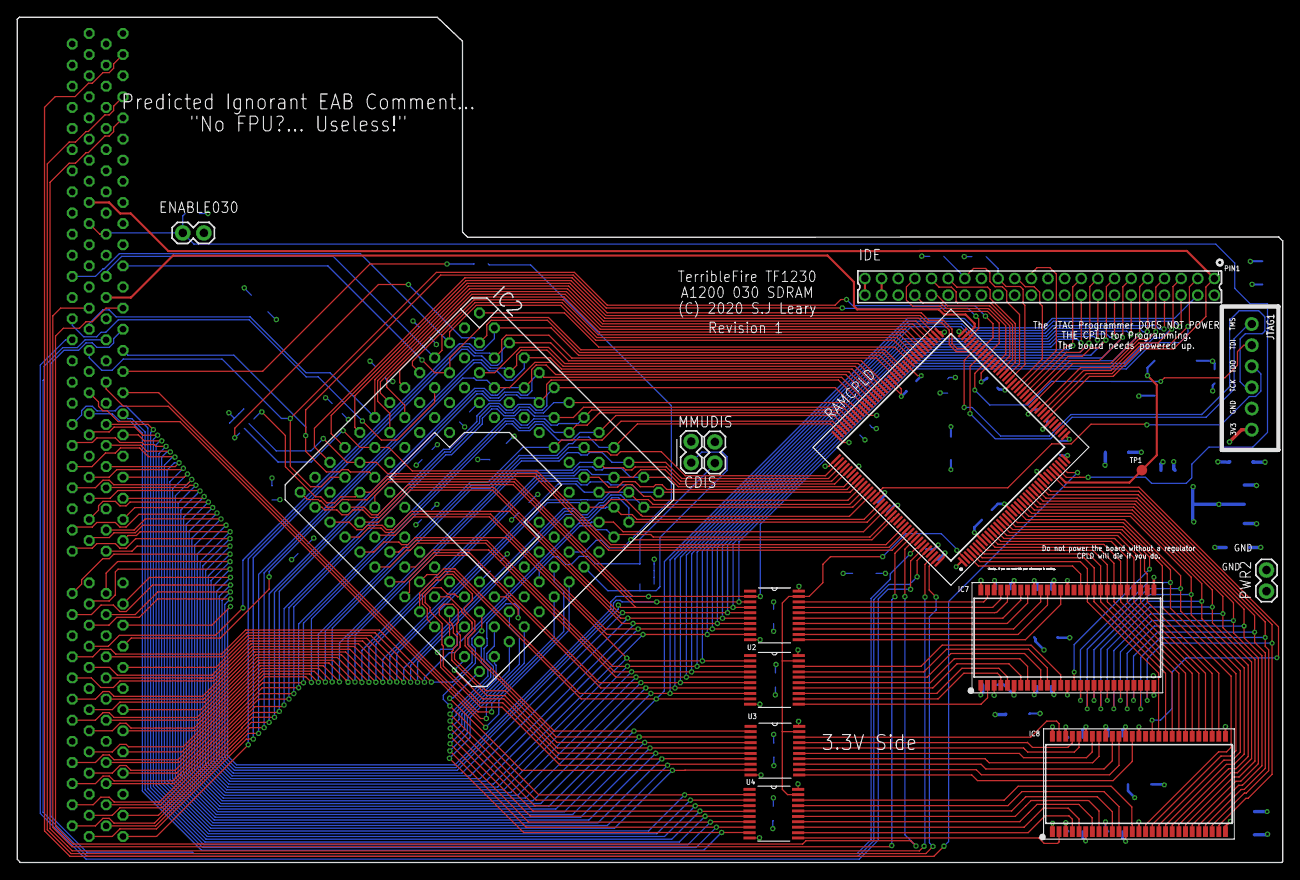
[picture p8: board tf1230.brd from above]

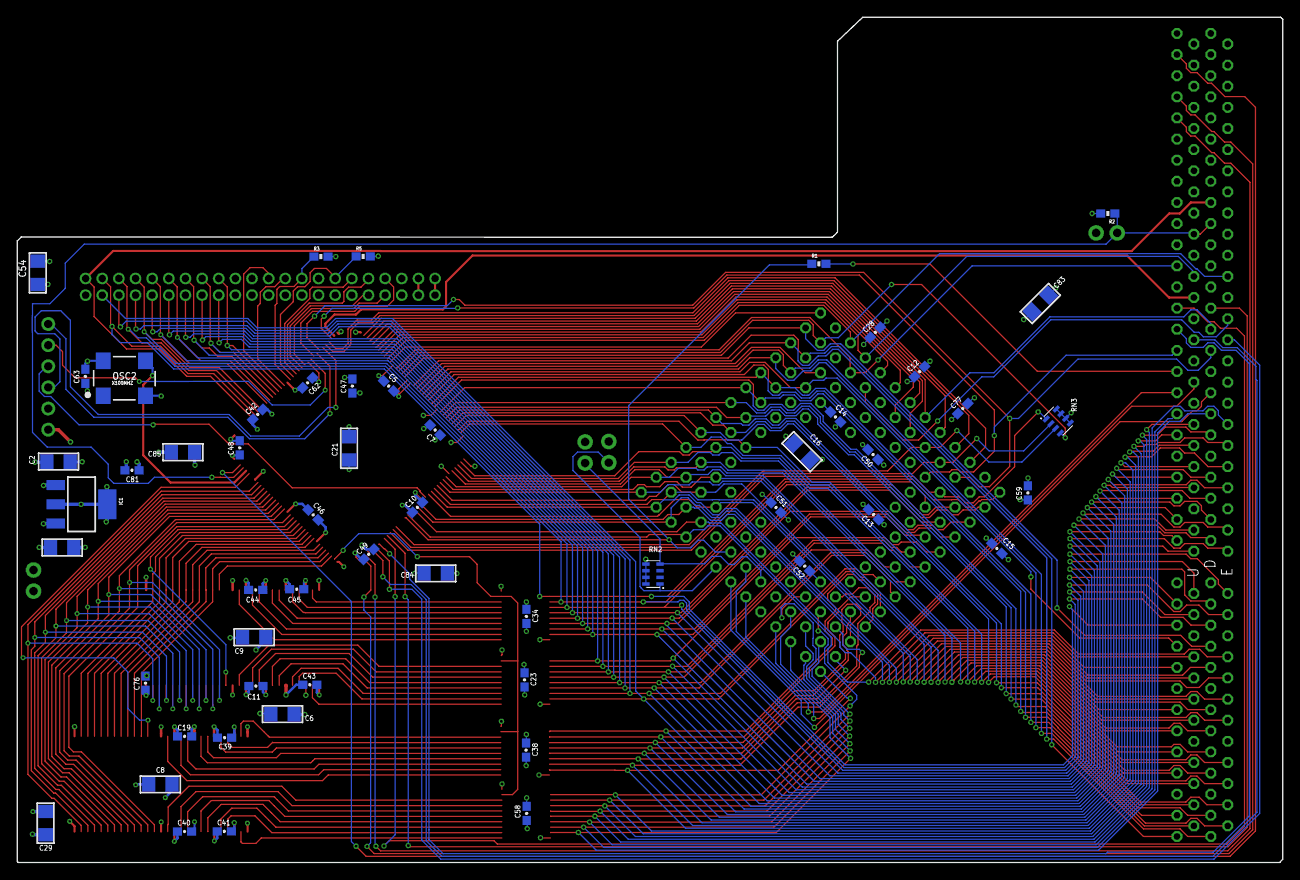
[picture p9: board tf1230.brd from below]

Board: 4 copper layers, 152.1 x 101.6 mm, 70 parts (55 on the bottom side), 178 nets.

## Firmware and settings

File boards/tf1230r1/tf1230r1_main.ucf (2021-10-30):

# Copyright (C) 2016-2017, Stephen J. Leary
# All rights reserved.
#
# This file is part of TF330/TF120 (Terrible Fire 030 Accelerator)
#
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
#Clocks
NET "CLK100M"		LOC="32";
NET "CLK100M" BUFG=CLK;
NET "CLK100M" TNM_NET = "CLK100M"; # gives the net clk a group name as CLK100M

NET "A<0>"      LOC="87";
NET "A<1>"      LOC="95";
NET "A<2>"      LOC="128";
NET "A<3>"      LOC="126";
NET "A<4>"      LOC="125";
NET "A<5>"      LOC="124";
NET "A<6>"      LOC="121";
NET "A<7>"      LOC="120";
NET "A<8>"      LOC="119";
NET "A<9>"      LOC="118";
NET "A<10>"      LOC="117";
NET "A<11>"      LOC="116";
NET "A<12>"      LOC="113";
NET "A<13>"      LOC="115";
NET "A<14>"      LOC="112";
NET "A<15>"      LOC="111";
NET "A<16>"      LOC="110";
NET "A<17>"      LOC="107";
NET "A<18>"      LOC="106";
NET "A<19>"      LOC="105";
NET "A<20>"      LOC="104";
NET "A<21>"      LOC="103";
NET "A<22>"      LOC="102";
NET "A<23>"      LOC="101";
NET "A<24>"      LOC="100";
NET "A<25>"      LOC="98";
NET "A<26>"      LOC="97";
NET "A<27>"      LOC="96";
NET "A<28>"      LOC="94";
NET "A<29>"      LOC="93";
NET "A<30>"      LOC="91";
NET "A<31>"      LOC="88";
NET "AB<2>"      LOC="59";
NET "AB<3>"      LOC="58";
NET "AB<4>"      LOC="60";
NET "ARAM<0>"      LOC="25";
NET "ARAM<1>"      LOC="26";
NET "ARAM<2>"      LOC="27";
NET "ARAM<3>"      LOC="28";
NET "ARAM<4>"      LOC="14";
NET "ARAM<5>"      LOC="13";
NET "ARAM<6>"      LOC="12";
NET "ARAM<7>"      LOC="11";
NET "ARAM<8>"      LOC="10";
NET "ARAM<9>"      LOC="9";
NET "ARAM<10>"      LOC="24";
NET "ARAM<11>"      LOC="7";
NET "ARAM<12>"      LOC="6";
NET "AS20"      LOC="140";
NET "AS30"      LOC="132";
NET "BA<0>"      LOC="23";
NET "BA<1>"      LOC="22";
NET "BERR"      LOC="75";
NET "BG30"      LOC="86";
NET "BGACK30"      LOC="92";
NET "BR20"      LOC="33";
NET "BR30"      LOC="83";
NET "CAS"      LOC="19";
NET "CBACK"      LOC="74";
NET "CBREQ"      LOC="68";
NET "CFGOUT"      LOC="34";
NET "CIIN"      LOC="69";
NET "CLK14M"      LOC="71";
NET "CLKCPU"      LOC="80";
NET "CLKRAM"      LOC="4";
NET "CLKRAME"      LOC="5";
NET "D<24>"      LOC="52";
NET "D<25>"      LOC="51";
NET "D<26>"      LOC="50";
NET "D<27>"      LOC="49";
NET "D<28>"      LOC="48";
NET "D<29>"      LOC="46";
NET "D<30>"      LOC="45";
NET "D<31>"      LOC="44";
NET "DQM<0>"      LOC="16";
NET "DQM<1>"      LOC="31";
NET "DQM<2>"      LOC="15";
NET "DQM<3>"      LOC="3";
NET "DS20"      LOC="139";
NET "DS30"      LOC="133";
NET "DS30ACK<0>"      LOC="79";
NET "DS30ACK<1>"      LOC="78";
NET "DSACK<0>"      LOC="135";
NET "DSACK<1>"      LOC="136";
NET "FC<0>"      LOC="85";
NET "FC<1>"      LOC="82";
NET "FC<2>"      LOC="81";
NET "HALT"      LOC="76";
NET "IDECS<0>"      LOC="64";
NET "IDECS<1>"      LOC="61";
NET "IDEINT"      LOC="57";
NET "IDEWAIT"      LOC="56";
NET "INT2"      LOC="143";
NET "IOR"      LOC="54";
NET "IOW"      LOC="53";
NET "PUNT"      LOC="142";
NET "RAMOE"     LOC="2";
NET "RAMCS"      LOC="21";
NET "RAMWE"      LOC="17";
NET "RAS"      LOC="20";
NET "RESET"      LOC="43";
NET "RSTO"      LOC="129";
NET "RW20"      LOC="138";
NET "RW30"      LOC="134";
NET "SIZ<0>"      LOC="66";
NET "SIZ<1>"      LOC="70";
NET "STERM"      LOC="77";

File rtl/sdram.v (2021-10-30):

`timescale 1ns / 1ps
/*
    Copyright (C) 2016-2017, Stephen J. Leary
    All rights reserved.
    
    This file is part of  TF330/TF120 (Terrible Fire 030 Accelerator).
 
	Attribution-NoDerivs 3.0 Unported

		CREATIVE COMMONS CORPORATION IS NOT A LAW FIRM AND DOES NOT PROVIDE
		LEGAL SERVICES. DISTRIBUTION OF THIS LICENSE DOES NOT CREATE AN
		ATTORNEY-CLIENT RELATIONSHIP. CREATIVE COMMONS PROVIDES THIS
		INFORMATION ON AN "AS-IS" BASIS. CREATIVE COMMONS MAKES NO WARRANTIES
		REGARDING THE INFORMATION PROVIDED, AND DISCLAIMS LIABILITY FOR
		DAMAGES RESULTING FROM ITS USE.

*/


module sdram(

           input        RESET,
           input        CLKCPU,
           input        CLK, 
           input        ACCESS,

           input [31:0] A,
           input [1:0]  SIZ,

           input        AS30,
           input        RW30,
           input        DS30,

           // cache and burst control
           output       CBACK,
           output       CIIN,
           input        CBREQ,
           output       STERM, 
           output       WAIT,

           // ram chip control
           //  SDRAM Control
           output			CLKRAME,
           output [12:0]    ARAM,
           output [1:0] 	BA,
           output			CAS,
           output [3:0] 	DQM,
           output			RAMWE,
           output			RAS,
           output			RAMCS,
           output			RAMOE,
           output [(12*8)-1:0]     COMMANDNAME


    );

`include "sdram_defines.v"

wire        ready;

wire        init_clke;
wire [3:0]  init_command;
wire [12:0] init_address;

reg STERM_D;
reg WAITSTATE;

reg [3:0]   command = CMD_NOP;
reg [3:0]   cycle   = 'd0;
reg [1:0]   bank    = 0;
reg [12:0]  address = 0;

wire refresh;

assign COMMANDNAME = cmd_name(ready ? init_command : command);

localparam MODE = { 3'b000, NO_WRITE_BURST, OP_MODE, CAS_LATENCY, ACCESS_TYPE, BURST_LENGTH};

sdram_init #
(
	.MODE(MODE)
)
INIT(

    .CLK    ( CLK           ),
    .CLKE   ( init_clke     ),
    .RESET  ( RESET         ),

    .CMD    ( init_command  ),
    .ARAM   ( init_address  ),
    .READY  ( ready         ),
    .REFRESH( refresh       )

);

reg refresh_d;
reg refresh_req;

localparam CYCLE_ACCESS = 'b0;
localparam CYCLE_REFRESH = 'b1;

localparam CYCLE_REFRESH_PRECHARGE = 5'b10001;
localparam CYCLE_REFRESH_AUTOREFRESH = CYCLE_REFRESH_PRECHARGE + RP_DELAY;
localparam CYCLE_REFRESH_COMPLETE = CYCLE_REFRESH_AUTOREFRESH  + RFC_DELAY;
localparam CYCLE_ACCESS_START = 5'b00000;
localparam CYCLE_ACCESS_RW = CYCLE_ACCESS_START + RASCAS_DELAY;
localparam CYCLE_ACCESS_COMPLETE = CYCLE_ACCESS_RW + 'd1;
localparam CYCLE_ACCESS_BW1 = CYCLE_ACCESS_COMPLETE + 1'd1;
localparam CYCLE_ACCESS_BW2 = CYCLE_ACCESS_BW1 + 1'd1;

reg BURSTING = 1'b0;
reg [1:0] BCOUNT = 2'b11;

// a read cycle at a tag aligned address. 
wire CAN_BURST = ({A[3:2]} != 2'b00) | CBREQ | ACCESS | ~RW30;
wire [1:0] RAMA = BURSTING ? {A[3:2]} : BCOUNT;

wire BURST_ENDING = (BCOUNT == 2'b11) | BURSTING;

reg cycle_type;
reg can_start;

reg WAIT_BLOCK = 1'b1;
reg [3:0] DQM_D;

always @(posedge CLK or negedge RESET) begin 

    if (RESET == 1'b0) begin 

        command     <= CMD_NOP;
        address     <= 'd0;
        bank        <= 'd0;
        refresh_req <= 'b1;
        refresh_d   <= 'b0;
        cycle       <= 'd0;
        cycle_type  <= 'd0;

    end else begin 

        command <= CMD_NOP;

        DQM_D[3] <= ACCESS | ~RW30 & (A[1] | A[0]);
        DQM_D[2] <= ACCESS | ~RW30 & ((~SIZ[1] & SIZ[0] & ~A[0]) | A[1]);
        DQM_D[1] <= ACCESS | ~RW30 & ((SIZ[1] & ~SIZ[0] & ~A[1] & ~A[0]) | (~SIZ[1] & SIZ[0] & ~A[1]) |(A[1] & A[0]));
        DQM_D[0] <= ACCESS | ~RW30 & ((~SIZ[1] & SIZ[0] & ~A[1] ) | (~SIZ[1] & SIZ[0] & ~A[0] ) | (SIZ[1] & ~A[1] & ~A[0] ) | (SIZ[1] & ~SIZ[0] & ~A[1]));

        if (AS30 == 1'b1) begin 

            can_start <= 1'b0;

        end

        // is a refresh required?
        refresh_d <= refresh;
        if ({refresh, refresh_d} == 2'b01) refresh_req <= 1'b0;

        if (cycle == 'd0) begin 
            
            WAIT_BLOCK <= 1'b1;
            BURSTING <= 1'b1;
            BCOUNT <= 'd0;
            
            if ((ready | can_start) == 1'b0) begin 

                address <= { A[23:11] };

                if (refresh_req == 1'b0) begin 

                    cycle_type <= CYCLE_REFRESH;
                    cycle[0] <= 'd1;

                end else if ((ACCESS | AS30) == 1'b0) begin 
                    
                    BURSTING <= CAN_BURST;
                    cycle_type <= CYCLE_ACCESS;
                    can_start <= 1'b1; 
                    cycle[0] <= 'd1;

                    address <= { A[23:11] };
                    command <= CMD_ACTIVE;
                    bank <= A[25:24];
                
                end

            end

        end else begin 

            // process the in progress cycle.
            cycle <= cycle + 'd1;

            casez  ({cycle_type, cycle}) 

                CYCLE_REFRESH_PRECHARGE: begin 
                    command			<= CMD_PRECHARGE;
		            address[10] 	<= 1'b1;      // precharge all banks
                end

                CYCLE_REFRESH_AUTOREFRESH: begin 
                    address[12:9] <= { 3'b001, A[26] };
                    command			<= CMD_AUTO_REFRESH;
                end

                CYCLE_REFRESH_COMPLETE: begin 
                    refresh_req <= 1'b1;
                    cycle <= 'd0;
                end

                CYCLE_ACCESS_RW: begin 
                    
                    address[9:0] <= { A[26], A[10:4], RAMA };
                    address[12:10] <= RW30 ?  3'b000 : 3'b001;
                    command <= RW30 ? CMD_READ : CMD_WRITE;
                    WAIT_BLOCK <= 'b0;
                    end                    

                CYCLE_ACCESS_COMPLETE: begin 
                    
                    address[9:0] <= { A[26], A[10:4], RAMA };
                    address[12:10] <= BURST_ENDING ? 3'b001 : 3'b000; // AUTO PRECHARGE ?
                    command <= RW30 ? CMD_READ : CMD_NOP;
                    BCOUNT <= BCOUNT + 'd1;
                    cycle <= BURST_ENDING ? 'd0 : CYCLE_ACCESS_BW1[3:0];

                end

                CYCLE_ACCESS_BW1: begin 
                    WAIT_BLOCK <= 'b1;
                end

                CYCLE_ACCESS_BW2: begin 
                    cycle <= CYCLE_ACCESS_RW[3:0];
                end 

                default: begin 
                    command <= CMD_NOP;
                end 

            endcase

        end

    end

end

always @(posedge CLKCPU or posedge AS30) begin	

    if (AS30 == 1'b1) begin 
        
        WAITSTATE <= 1'b1;
        STERM_D <= 1'b1;

    end else begin 

        WAITSTATE <= ACCESS | DS30 | WAIT_BLOCK;
        STERM_D <= WAIT_BLOCK;

    end
end

assign RAMOE = ACCESS;
assign DQM = DQM_D;

assign CIIN = ~ACCESS;
assign CBACK = BURSTING | CBREQ;
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

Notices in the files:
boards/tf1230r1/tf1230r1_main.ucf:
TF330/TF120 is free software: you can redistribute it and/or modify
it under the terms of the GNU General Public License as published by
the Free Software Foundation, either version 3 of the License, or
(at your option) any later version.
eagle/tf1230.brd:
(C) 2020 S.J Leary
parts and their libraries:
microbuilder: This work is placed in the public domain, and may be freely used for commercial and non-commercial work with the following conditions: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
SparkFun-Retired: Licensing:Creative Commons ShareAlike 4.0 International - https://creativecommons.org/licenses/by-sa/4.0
